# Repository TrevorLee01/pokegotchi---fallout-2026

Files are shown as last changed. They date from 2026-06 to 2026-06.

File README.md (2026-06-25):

# Pokegotchi
tamagotchi project by Trevor Lee

ONSHAPE LINK: https://cad.onshape.com/documents/4788cfc2c41ccbd3b3bb658b/w/c8008663c56e0ba217e7b347/e/ed1d7d4fd3640974190b7d9b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

BOM INCLUDED IN THE FILES! "BOM.csv", bottom of this README, or: https://docs.google.com/spreadsheets/d/1ZSV7nk1klidvS7acBAQEKFNUl_y9adzhBfaWMznL6cg/edit?gid=0#gid=0

______________



# What is a Pokegotchi?

This pokegotchi comes with 3 whole pokemons
- Snorlax
- Solosis
- Eevee
However, Eevee comes with 5 different types of Eeveelution depending on the exact environment (a secret). Play to find out which eeveelution you end up getting!

The possible 5 includes:
- umbreon
- leafeon
- slyveon
- glaceon
- espeon

____
# Features

The unique features of this tamagotchi are
- internal clock ( to tell between day and night)
- LDR (to tell how dark it is)

(and a completely different ESP32 :D)

____
# Why did I make it?

Through my entire childhood, I've always been into some type of media related to Pokemon. Despite being it a common hobby or interest, that never discouraged me to discontinue the love I have for Pokemon. 
I think it's such a fundamental piece to my development and I want to physically manifest the fondness by utilizing the hardware opportunity given by fallout. 

____
# Pictures‼️

Here is the pcb.







Here is the CAD.



Here is the render.



____
# How It Works ╰(°▽°)╯

Turn the Pokegotchi on and select one out of three Pokémon that you want to take care of: Snorlax, Solosis, or Eevee.

The built-in real-time clock (RTC) will help you keep track of the current time, enabling the device to know whether it is day or night. In addition, the light-dependent resistor (LDR) will detect how bright the surrounding environment is and make your Pokémon respond accordingly.

Should you pick Eevee, it will evolve into one of five unique Eeveelutions, depending both on your in-game actions and some hidden environmental factors.

Use the buttons on the Pokegotchi to navigate through the menus.

____
# How to Build Your Own Pokegotchi :D

1. Print the Case: Download the .step files from the repository and use a 3D printer to print the front case and back case.

2. Solder the Components: Solder all the components to the custom PCB, including the ESP32, RTC IC, light sensor (LDR), display, buttons, and other hardware as specified in the bill of materials.

3. Place the Hardware: Install the PCB inside the printed case using 2 M3x10 screws, and then secure the top of the case using 3 M3x5 screws. Don't forget to place the battery inside its pocket, and connect it to the pinheader.

4. Upload the Firmware: Download the .ino file from the repository and flash Pokegotchi firmware onto the ESP32.

5. Get Ready for an Exciting Journey: Turn on the device, select a Pokémon, and start training your Pokegotchi!

____
# BOM

**Total Cost: $44.40**

| Item | Individual Cost | Quantity | Cost | Link | Additional Notes |
|---|---|---|---|---|---|
| ESP32-S3-WROOM-1-N16R8 MCU | $6.76 | 1 | $6.76 | https://www.digikey.com/en/products/detail/espressif-systems/ESP32-S3-WROOM-1-N16R8/16162642 | |
| TYPE-C-31-M-12 USB-C Receptacle | $0.19 | 5 | $0.93 | https://www.lcsc.com/product-detail/C165948.html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 | 4 extra, MOQ 5 |
| XHXDZ 1207-P6.5MM Buzzer | $0.50 | 10 | $5.03 | https://www.aliexpress.us/item/3256810135642750.html | 9 extra, MOQ 10 |
| MCP73831T-2ATI/OT Charger | $0.76 | 1 | $0.76 | https://www.digikey.com/en/products/detail/microchip-technology/MCP73831T-2ATI-OT/964303 | |
| AP2112K-3.3TRG1 Voltage Regulator | $0.25 | 1 | $0.25 | https://www.digikey.com/en/products/detail/diodes-incorporated/AP2112K-3-3TRG1/4470746 | |
| 1825910-6 Tactile Switch | $0.13 | 3 | $0.39 | https://www.digikey.com/en/products/detail/te-connectivity-alcoswitch-switches/1825910-6/1632536 | duplicated entry in source list |
| TS-104-T-A Connector | $1.06 | 1 | $1.06 | https://www.digikey.com/en/products/detail/samtec-inc/TS-104-T-A/1105490 | |
| M20-9990246 Connector | $0.10 | 1 | $0.10 | https://www.digikey.com/en/products/detail/harwin-inc/M20-9990246/3728226 | |
| 1825910-6 Tactile Switch (duplicate) | $0.13 | 3 | $0.39 | https://www.digikey.com/en/products/detail/te-connectivity-alcoswitch-switches/1825910-6/1632536 | appears twice in CSV |
| RC0805JR-075K1L Resistor | $0.10 | 2 | $0.20 | https://www.digikey.com/en/products/detail/yageo/RC0805JR-075K1L/728338 | |
| RC0805FR-072KL Resistor | $0.10 | 1 | $0.10 | https://www.digikey.com/en/products/detail/yageo/RC0805FR-072KL/727664 | |
| RC0805FR-0710KL Resistor | $0.10 | 3 | $0.30 | https://www.digikey.com/en/products/detail/yageo/RC0805FR-0710KL/727535 | |
| RC0805FR-074K7L Resistor | $0.10 | 2 | $0.20 | https://www.digikey.com/en/products/detail/yageo/RC0805FR-074K7L/727929 | |
| GL12528 LDR | $0.31 | 5 | $1.56 | https://www.lcsc.com/product-detail/C559386.html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 | 4 extra, MOQ 5 |
| CL21B105KAFNNNE Capacitor | $0.10 | 1 | $0.10 | https://www.digikey.com/en/products/detail/samsung-electro-mechanics/CL21B105KAFNNNE/3886724 | |
| CL21A475KAQNNNE Capacitor | $0.11 | 2 | $0.22 | https://www.digikey.com/en/products/detail/samsung-electro-mechanics/CL21A475KAQNNNE/3886902 | |
| HS96L03W2C03 Screen | $1.87 | 1 | $1.87 | https://www.aliexpress.us/item/2251832337475453.html | |
| DS3231MZ+TRL Clock | $12.68 | 1 | $12.68 | https://www.digikey.com/en/products/detail/analog-devices-inc-maxim-integrated/DS3231MZ-TRL/2754408 | |
| Battery | $6.20 | 1 | $6.20 | https://www.aliexpress.us/item/3256808658204287.html | |
| PCB | $0.40 | 5 | $2.00 | https://cart.jlcpcb.com/quote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 | |
| PLA Housing | — | — | — | — | |
| M3 x 10mm Socket Cap Head Screws | $0.75 | 2 | $1.50 | https://accu-components.com/us/metric-cap-head-screws/16004-SSCF-M3-10-12-9 | |
| M3 x 5mm Socket Cap Head Screws | $0.45 | 4 | $1.80 | https://accu-components.com/us/metric-cap-head-screws/16001-SSCF-M3-5-12-9 | 4 is cheaper than 3 |

____
# Credits

Onshape (CAD design)

GitHub (project hosting + documentation)

KiCad (PCB design workflow)

ESP32 (hardware platform)

Hack Club / Fallout (project opportunity + support)

Pokémon for the original inspiration behind the concept

Special thanks to Youna Son for help with art

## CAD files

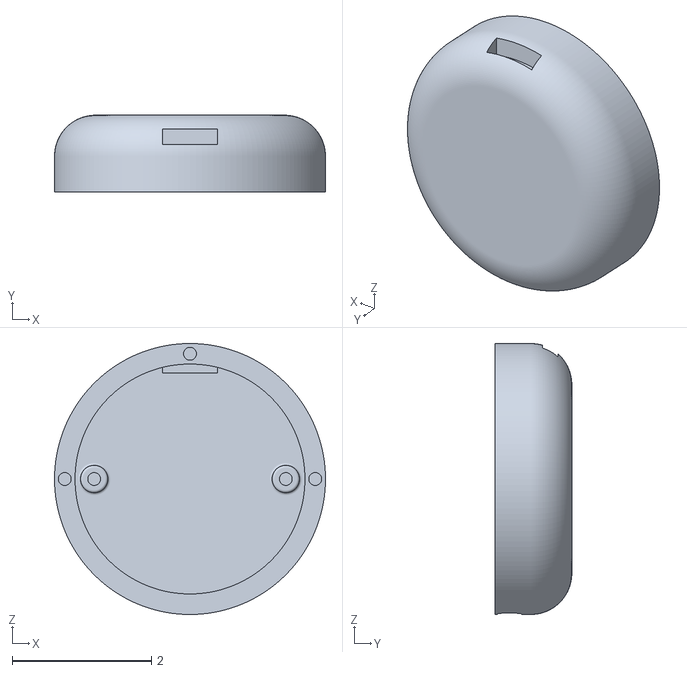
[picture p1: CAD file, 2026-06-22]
CAD/pokegotchi_bottom.stl
3.90 x 1.10 x 3.90

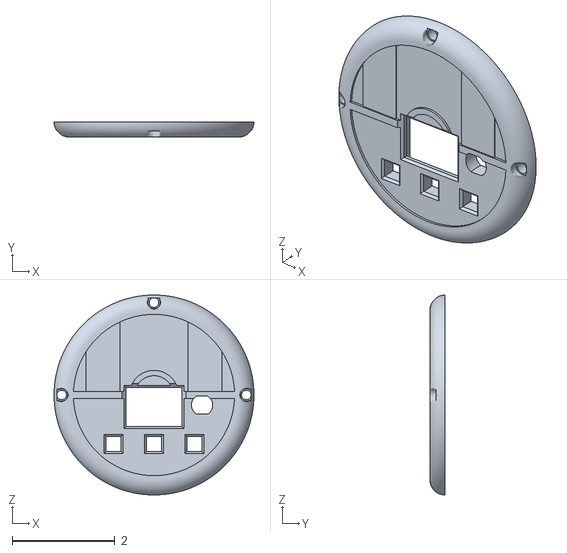
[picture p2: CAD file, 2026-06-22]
CAD/pokegotchi_top.stl
3.90 x 0.295 x 3.90

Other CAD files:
CAD/FINAL ASSEMBLY.step

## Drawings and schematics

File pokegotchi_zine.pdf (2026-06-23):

# P KÉG TCHI

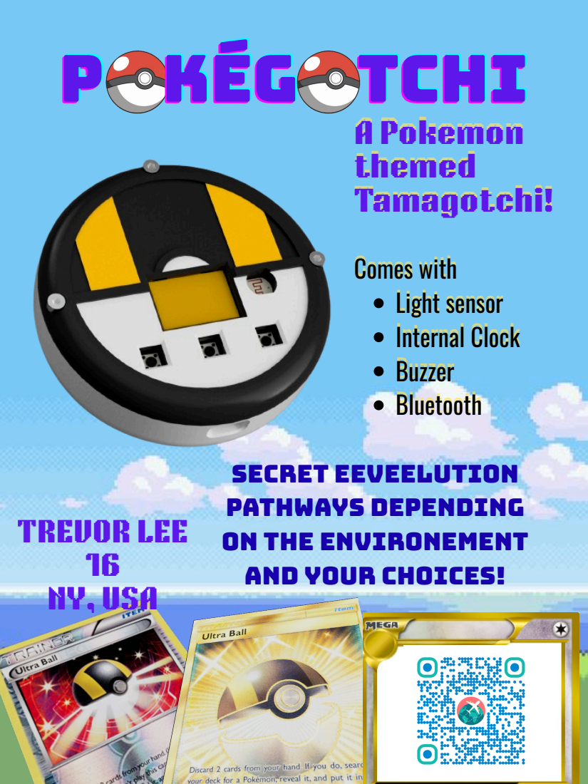
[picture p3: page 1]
TREVOR LEE 16 NY, USA; AA P Pookkeemmoonn tthheemmeedd TTaammaaggoottcchhii!!; CCoommeess wwiitthh LLiigghhtt sseennssoorr IInntteerrnnaall CClloocckk BBuuzzzzeerr BBlluueettooootthh; A Pokemon themed Tamagotchi!; Comes with Light sensor Internal Clock Buzzer Bluetooth

Secret Eeveelution
pathways depending
on the environement
and your choices!

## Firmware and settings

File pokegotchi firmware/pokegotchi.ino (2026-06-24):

#include <Arduino.h>
#include <Wire.h>
#include <Adafruit_GFX.h>
#include <Adafruit_SSD1306.h>
#include <RTClib.h>
#include <Preferences.h>

// Libraries used:
// Arduino.h: normal Arduino functions, pins, millis, tone, Serial
// Wire.h: I2C bus for the OLED and DS3231 RTC
// Adafruit_GFX.h: graphics base library for the OLED
// Adafruit_SSD1306.h: 128x64 OLED driver
// RTClib.h: DS3231 real-time clock driver
// Preferences.h: ESP32 flash storage for saved pet state

const byte GOTCHI_SDA_PIN = 11;
const byte GOTCHI_SCL_PIN = 12;
const byte GOTCHI_SW1_PIN = 4;
const byte GOTCHI_SW2_PIN = 5;
const byte GOTCHI_SW3_PIN = 6;
const byte GOTCHI_BUZZER_PIN = 7;
const byte GOTCHI_LDR_PIN = 1;

const byte GOTCHI_OLED_WIDTH = 128;
const byte GOTCHI_OLED_HEIGHT = 64;
const byte GOTCHI_OLED_ADDR = 0x3C;

const byte GOTCHI_STAT_MAX = 100;
const byte GOTCHI_FRIENDSHIP_EVOLVE = 80;
const byte GOTCHI_SYLVEON_FRIENDSHIP = 95;
const int GOTCHI_BRIGHT_LIGHT = 2800;
const int GOTCHI_DARK_LIGHT = 900;
const byte GOTCHI_DAY_START = 6;
const byte GOTCHI_NIGHT_START = 20;

const unsigned long GOTCHI_TICK_MS = 1000;
const unsigned long GOTCHI_SAVE_MS = 30000;

Adafruit_SSD1306 display(GOTCHI_OLED_WIDTH, GOTCHI_OLED_HEIGHT, &Wire, -1);
RTC_DS3231 rtc;
Preferences prefs;

enum Species {
  GOTCHI_NONE,
  GOTCHI_EEVEE,
  GOTCHI_SNORLAX,
  GOTCHI_SOLOSIS,
  GOTCHI_UMBREON,
  GOTCHI_LEAFEON,
  GOTCHI_SYLVEON,
  GOTCHI_GLACEON,
  GOTCHI_ESPEON
};

enum Screen {
  GOTCHI_STARTER_SCREEN,
  GOTCHI_HOME_SCREEN,
  GOTCHI_MENU_SCREEN,
  GOTCHI_STATS_SCREEN,
  GOTCHI_MESSAGE_SCREEN
};

struct PetState {
  uint32_t magic = 0x504F4B45;  // POKE
  uint16_t version = 1;
  Species species = GOTCHI_NONE;
  uint32_t createdUnix = 0;
  uint32_t lastUpdateUnix = 0;
  uint32_t careCount = 0;
  uint32_t playCount = 0;
  byte hunger = 70;
  byte happiness = 65;
  byte energy = 80;
  byte friendship = 50;
  bool asleep = false;
  bool evolved = false;
};

struct ButtonState {
  byte pin;
  bool stable = HIGH;
  bool lastRead = HIGH;
  unsigned long changedAt = 0;
};

PetState pet;
ButtonState sw1 = {GOTCHI_SW1_PIN};
ButtonState sw2 = {GOTCHI_SW2_PIN};
ButtonState sw3 = {GOTCHI_SW3_PIN};

Screen screen = GOTCHI_STARTER_SCREEN;
byte starterChoice = 0;
byte menuChoice = 0;
bool rtcReady = false;
unsigned long lastTick = 0;
unsigned long lastSave = 0;
unsigned long messageUntil = 0;
char messageText[22] = "";

byte clampStat(int value) {
  if (value < 0) return 0;
  if (value > GOTCHI_STAT_MAX) return GOTCHI_STAT_MAX;
  return value;
}

byte changeStat(byte value, int amount) {
  return clampStat((int)value + amount);
}

bool isDay(byte hour) {
  return hour >= GOTCHI_DAY_START && hour < GOTCHI_NIGHT_START;
}

bool isNight(byte hour) {
  return !isDay(hour);
}

const char* speciesName(Species species) {
  switch (species) {
    case GOTCHI_EEVEE: return "Eevee";
    case GOTCHI_SNORLAX: return "Snorlax";
    case GOTCHI_SOLOSIS: return "Solosis";
    case GOTCHI_UMBREON: return "Umbreon";
    case GOTCHI_LEAFEON: return "Leafeon";
    case GOTCHI_SYLVEON: return "Sylveon";
    case GOTCHI_GLACEON: return "Glaceon";
    case GOTCHI_ESPEON: return "Espeon";
    default: return "No Pokemon";
  }
}

uint32_t nowUnix() {
  if (rtcReady) return rtc.now().unixtime();
  return millis() / 1000;
}

byte currentHour() {
  if (rtcReady) return rtc.now().hour();
  return (millis() / 3600000UL) % 24;
}

byte currentMinute() {
  if (rtcReady) return rtc.now().minute();
  return (millis() / 60000UL) % 60;
}

int lightRaw() {
  return analogRead(GOTCHI_LDR_PIN);
}

bool petExists() {
  return pet.species != GOTCHI_NONE;
}

void beep(int freq = 1600, int ms = 40) {
  tone(GOTCHI_BUZZER_PIN, freq, ms);
}

bool pressed(ButtonState& button) {
  const unsigned long gotchiDebounceMs = 35;
  bool reading = digitalRead(button.pin);
  unsigned long now = millis();

  if (reading != button.lastRead) {
    button.lastRead = reading;
    button.changedAt = now;
  }

  if (now - button.changedAt < gotchiDebounceMs) return false;
  if (reading == button.stable) return false;

  button.stable = reading;
  return button.stable == LOW;
}

void savePet() {
  prefs.putBytes("pet", &pet, sizeof(pet));
}

bool loadPet() {
  if (!prefs.isKey("pet")) return false;
  if (prefs.getBytesLength("pet") != sizeof(pet)) return false;
  prefs.getBytes("pet", &pet, sizeof(pet));
  return pet.magic == 0x504F4B45 && pet.version == 1;
}

void showMessage(const char* text) {
  snprintf(messageText, sizeof(messageText), "%s", text);
  messageUntil = millis() + 1600;
  screen = GOTCHI_MESSAGE_SCREEN;
  beep(2200, 50);
}

void chooseStarter() {
  pet = PetState();
  if (starterChoice == 0) pet.species = GOTCHI_EEVEE;
  if (starterChoice == 1) pet.species = GOTCHI_SNORLAX;
  if (starterChoice == 2) pet.species = GOTCHI_SOLOSIS;
  pet.createdUnix = nowUnix();
  pet.lastUpdateUnix = pet.createdUnix;
  savePet();
  showMessage("Welcome!");
}

void updatePet() {
  if (!petExists()) return;

  uint32_t now = nowUnix();
  if (pet.lastUpdateUnix == 0 || now <= pet.lastUpdateUnix) {
    pet.lastUpdateUnix = now;
    return;
  }

  uint32_t minutes = (now - pet.lastUpdateUnix) / 60;
  if (minutes == 0) return;

  byte hour = currentHour();
  int light = lightRaw();

  for (uint32_t i = 0; i < minutes; i++) {
    if (i % 12 == 0) pet.hunger = changeStat(pet.hunger, -1);
    if (i % 20 == 0) pet.happiness = changeStat(pet.happiness, -1);

    if (pet.asleep || isNight(hour)) {
      pet.energy = changeStat(pet.energy, 1);
    } else if (i % 15 == 0) {
      pet.energy = changeStat(pet.energy, -1);
    }

    if (pet.hunger > 65 && pet.happiness > 65 && i % 30 == 0) {
      pet.friendship = changeStat(pet.friendship, 1);
    }

    if ((pet.hunger < 20 || pet.happiness < 20) && i % 20 == 0) {
      pet.friendship = changeStat(pet.friendship, -1);
    }
  }

  pet.asleep = isNight(hour) && light < GOTCHI_DARK_LIGHT;
  pet.lastUpdateUnix += minutes * 60;
}

const char* feedPet() {
  pet.hunger = changeStat(pet.hunger, 18);
  pet.happiness = changeStat(pet.happiness, 3);
  pet.friendship = changeStat(pet.friendship, 2);
  pet.careCount++;
  return "Yum!";
}

const char* playWithPet() {
  if (pet.energy < 10 || pet.hunger < 10) {
    pet.happiness = changeStat(pet.happiness, -2);
    return "Too tired.";
  }
  pet.happiness = changeStat(pet.happiness, 12);
  pet.friendship = changeStat(pet.friendship, 4);
  pet.energy = changeStat(pet.energy, -9);
  pet.hunger = changeStat(pet.hunger, -5);
  pet.playCount++;
  pet.careCount++;
  return "Fun!";
}

const char* restPet() {
  pet.asleep = !pet.asleep;
  if (pet.asleep) return "Sleepy...";
  return "Awake!";
}

const char* careForPet() {
  pet.happiness = changeStat(pet.happiness, 7);
  pet.friendship = changeStat(pet.friendship, 5);
  pet.careCount++;
  return "Happy!";
}

const char* evolvePet() {
  if (pet.species != GOTCHI_EEVEE || pet.evolved) return "No evolve.";
  if (pet.friendship < GOTCHI_FRIENDSHIP_EVOLVE) return "Needs bond.";

  byte hour = currentHour();
  int light = lightRaw();

  if (pet.friendship >= GOTCHI_SYLVEON_FRIENDSHIP && pet.playCount >= 12) {
    pet.species = GOTCHI_SYLVEON;
  } else if (light >= GOTCHI_BRIGHT_LIGHT) {
    pet.species = GOTCHI_LEAFEON;
  } else if (light <= GOTCHI_DARK_LIGHT) {
    pet.species = GOTCHI_GLACEON;
  } else if (isNight(hour)) {
    pet.species = GOTCHI_UMBREON;
  } else {
    pet.species = GOTCHI_ESPEON;
  }

  pet.evolved = true;
  pet.happiness = GOTCHI_STAT_MAX;
  pet.friendship = GOTCHI_STAT_MAX;
  return "Evolved!";
}

void header(const char* title) {
  display.setTextSize(1);
  display.setTextColor(SSD1306_WHITE);
  display.setCursor(0, 0);
  display.print(title);
  display.drawLine(0, 9, GOTCHI_OLED_WIDTH - 1, 9, SSD1306_WHITE);
}

void statBar(int x, int y, const char* label, byte value) {
  display.setCursor(x, y);
  display.print(label);
  display.drawRect(x + 32, y, 72, 8, SSD1306_WHITE);
  byte fill = map(value, 0, GOTCHI_STAT_MAX, 0, 70);
  display.fillRect(x + 33, y + 1, fill, 6, SSD1306_WHITE);
}

void drawStarter() {
  const char* starters[] = {"Eevee", "Snorlax", "Solosis"};
  display.clearDisplay();
  header("Choose starter");
  for (byte i = 0; i < 3; i++) {
    display.setCursor(10, 18 + i * 14);
    display.print(i == starterChoice ? "> " : "  ");
    display.print(starters[i]);
  }
  display.display();
}

void drawHome() {
  display.clearDisplay();
  header(speciesName(pet.species));

  byte hour = currentHour();
  byte minute = currentMinute();

  display.setCursor(0, 12);
  if (hour < 10) display.print("0");
  display.print(hour);
  display.print(":");
  if (minute < 10) display.print("0");
  display.print(minute);
  display.print(pet.asleep ? "  zZ" : "  awake");

  statBar(0, 25, "Food", pet.hunger);
  statBar(0, 38, "Joy ", pet.happiness);
  statBar(0, 51, "Bond", pet.friendship);

  display.setCursor(86, 12);
  display.print("L:");
  display.print(lightRaw() / 16);
  display.display();
}

void drawMenu() {
  const char* items[] = {"Feed", "Play", "Rest", "Care", "Evolve", "Stats"};
  display.clearDisplay();
  header(speciesName(pet.species));

  for (byte row = 0; row < 4; row++) {
    byte item = (menuChoice / 4) * 4 + row;
    if (item >= 6) break;
    display.setCursor(8, 15 + row * 12);
    display.print(item == menuChoice ? "> " : "  ");
    display.print(items[item]);
  }
  display.display();
}

void drawStats() {
  uint32_t age = 0;
  if (pet.createdUnix > 0 && nowUnix() > pet.createdUnix) {
    age = (nowUnix() - pet.createdUnix) / 86400;
  }

  display.clearDisplay();
  header("Stats");
  display.setCursor(0, 13);
  display.print(speciesName(pet.species));
  display.print(" age ");
  display.print(age);
  display.print("d");
  display.setCursor(0, 25);
  display.print("Energy ");
  display.print(pet.energy);
  display.setCursor(0, 37);
  display.print("Light ");
  display.print(lightRaw());
  display.setCursor(0, 49);
  display.print("Care ");
  display.print(pet.careCount);
  display.display();
}

void drawMessage() {
  display.clearDisplay();
  header(speciesName(pet.species));
  display.setCursor(0, 25);
  display.print(messageText);
  display.display();
}

void drawScreen() {
  if (screen == GOTCHI_STARTER_SCREEN) drawStarter();
  else if (screen == GOTCHI_HOME_SCREEN) drawHome();
  else if (screen == GOTCHI_MENU_SCREEN) drawMenu();
  else if (screen == GOTCHI_STATS_SCREEN) drawStats();
  else if (screen == GOTCHI_MESSAGE_SCREEN) drawMessage();
}

void doMenuAction() {
  const char* result = "";

  if (menuChoice == 0) result = feedPet();
  if (menuChoice == 1) result = playWithPet();
  if (menuChoice == 2) result = restPet();
  if (menuChoice == 3) result = careForPet();
  if (menuChoice == 4) result = evolvePet();
  if (menuChoice == 5) {
    screen = GOTCHI_STATS_SCREEN;
    beep();
    return;
  }

  savePet();
  showMessage(result);
}

void setup() {
  Serial.begin(115200);

  pinMode(GOTCHI_SW1_PIN, INPUT_PULLUP);
  pinMode(GOTCHI_SW2_PIN, INPUT_PULLUP);
  pinMode(GOTCHI_SW3_PIN, INPUT_PULLUP);
  pinMode(GOTCHI_BUZZER_PIN, OUTPUT);
  pinMode(GOTCHI_LDR_PIN, INPUT);
  analogReadResolution(12);

  Wire.begin(GOTCHI_SDA_PIN, GOTCHI_SCL_PIN);
  Wire.setClock(400000);

  display.begin(SSD1306_SWITCHCAPVCC, GOTCHI_OLED_ADDR);
  display.clearDisplay();
  display.setTextColor(SSD1306_WHITE);
  display.setCursor(0, 0);
  display.println("Pokegotchi");
  display.println("Booting...");
  display.display();

  rtcReady = rtc.begin();
  if (rtcReady && rtc.lostPower()) {
    rtc.adjust(DateTime(F(__DATE__), F(__TIME__)));
  }

  prefs.begin("pokegotchi", false);
  if (loadPet() && petExists()) screen = GOTCHI_HOME_SCREEN;
  else screen = GOTCHI_STARTER_SCREEN;

  drawScreen();
}

void loop() {
  bool left = pressed(sw1);
  bool select = pressed(sw2);
  bool right = pressed(sw3);
  bool anyButton = left || select || right;
  unsigned long now = millis();

  if (now - lastTick >= GOTCHI_TICK_MS) {
    lastTick = now;
    updatePet();
    drawScreen();
  }

  if (screen == GOTCHI_MESSAGE_SCREEN && now > messageUntil) {
    screen = GOTCHI_HOME_SCREEN;
    drawScreen();
  }

  if (screen == GOTCHI_STARTER_SCREEN) {
    if (left) starterChoice = (starterChoice + 2) % 3;
    if (right) starterChoice = (starterChoice + 1) % 3;
    if (select) chooseStarter();
  } else if (screen == GOTCHI_HOME_SCREEN) {
    if (anyButton) {
      menuChoice = 0;
      screen = GOTCHI_MENU_SCREEN;
      beep();
    }
  } else if (screen == GOTCHI_MENU_SCREEN) {
    if (left) menuChoice = (menuChoice + 5) % 6;
    if (right) menuChoice = (menuChoice + 1) % 6;
    if (select) doMenuAction();
  } else if (screen == GOTCHI_STATS_SCREEN) {
    if (anyButton) {
      screen = GOTCHI_HOME_SCREEN;
      beep();
    }
  }

  if (anyButton) drawScreen();

  if (petExists() && now - lastSave >= GOTCHI_SAVE_MS) {
    lastSave = now;
    savePet();
  }
}
